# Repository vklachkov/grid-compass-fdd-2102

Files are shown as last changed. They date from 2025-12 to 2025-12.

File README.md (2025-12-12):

# Reverse Engineering of 2102 Floppy Drive

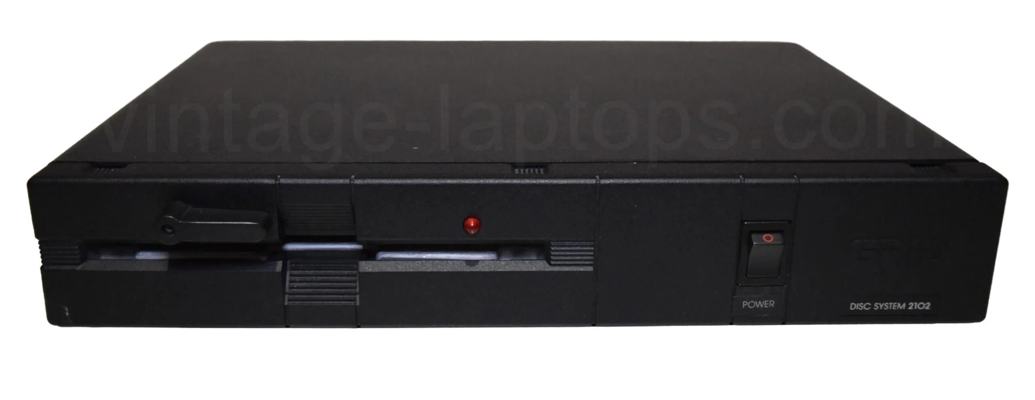
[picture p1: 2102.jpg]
Photo of 2102

Photo was taken from the [vintage-laptops.com](https://vintage-laptops.com/en/per-gridcompass1121/).

This is a project to reverse engineer the 2102 floppy drive from 1983 for the GRiD Compass laptop. The project is for fun and to fix bugs in the [blackgpib](https://github.com/vklachkov/blackgpib) project.

Current status:

2. Complete schematics by [@JDat](https://github.com/JDat).
3. Full dump of PAL chip by [@JDat](https://github.com/JDat).
4. Firmware reverse engineering is ~80% complete by [me](https://github.com/vklachkov) and Kirill from [Xecut Hackspace](https://xecut.me/).

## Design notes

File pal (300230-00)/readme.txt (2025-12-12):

This folder contains information about
GRiD 300230-00 (PAL16L8) IC used in 2102 Portable floppy.

pal16l8.txt - initial dump made with arduino EEPROM programmer/dumper
This file in compatible with Logic Friday truth table input format.
Dump made on 2024.07.21. 09:30 UTC

pal16l8.bin - binary reperesentation of 300230-00 it we assume it is
ROM lookup table (similar approach to Commodore PLA address chip).

16L8_pins_bin_dump.jpg - pinout for assmuming it is ROM lookup table

PAL16L8_dumper folder contains arduino source code and schematics for dumper

c_equvalent folder contains Simple C program to generate the same binary file
as pal16l8.bin and for future research

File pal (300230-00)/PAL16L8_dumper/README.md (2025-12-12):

This is quick and dirty project
to convert my EEPROM programmer
into PAL/GAL dumper/reversing/research platform

Arduino I2C EEPROM Programmer for SST39SF010A/SST39SF020A/SST39SF040A AT29C010A

This code should be compiled by the Arduino IDE and run on an Arduino UNO.

Code based on:
http://danceswithferrets.org/geekblog/?page_id=903
https://github.com/TSwimson/eeprom-writer

and Chris Baird’s Python script

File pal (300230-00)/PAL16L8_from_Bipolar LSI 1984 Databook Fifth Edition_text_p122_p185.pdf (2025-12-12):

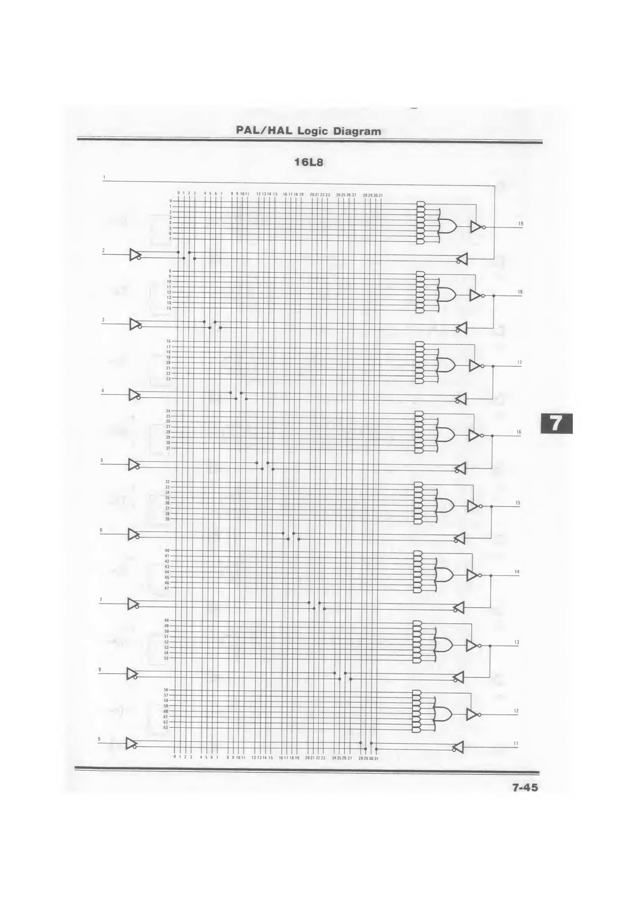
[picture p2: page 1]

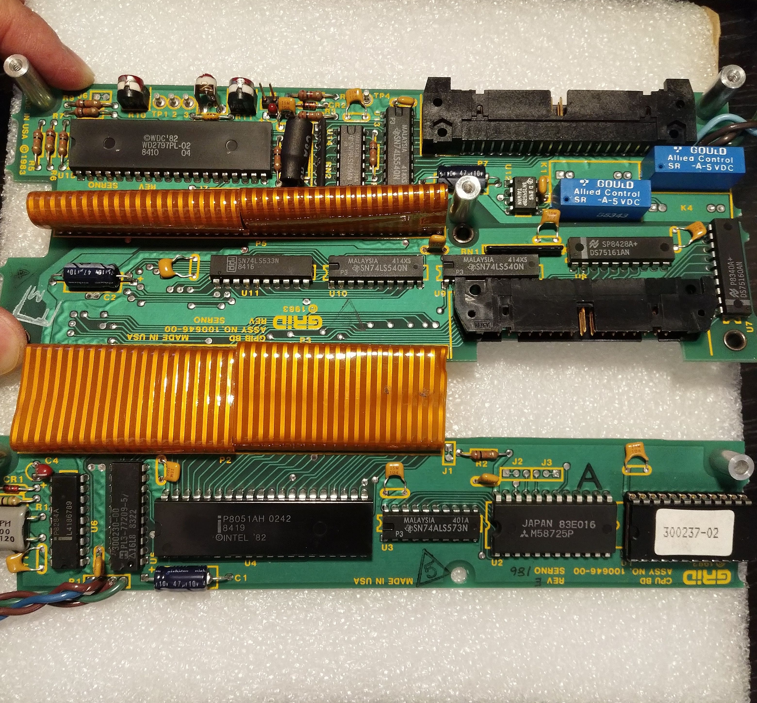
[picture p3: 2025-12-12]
photos/2102 (1983) boards.jpg

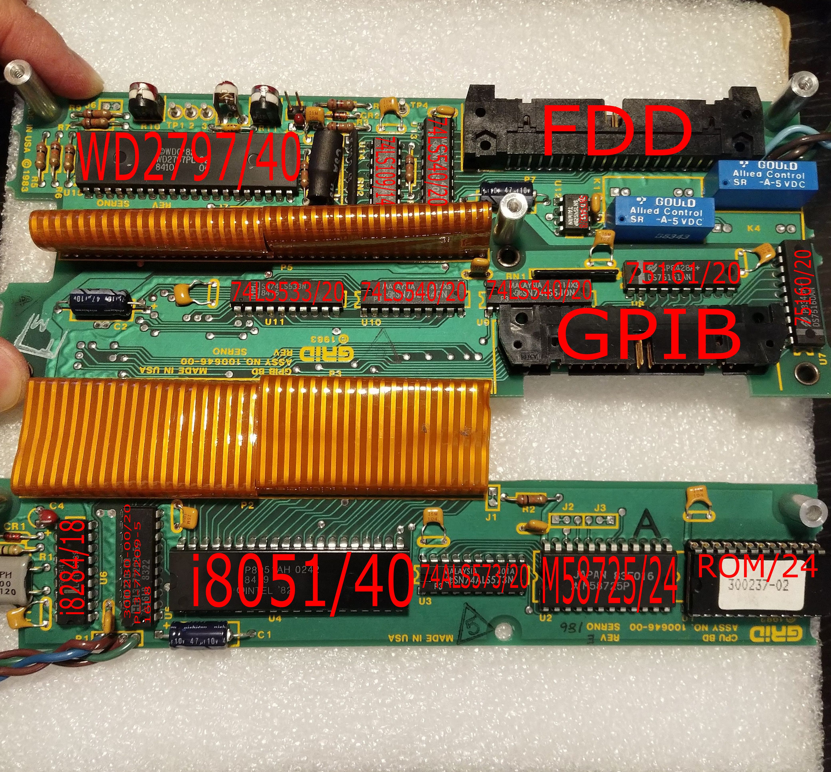
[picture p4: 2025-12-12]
photos/2102 (1983) boards with ICs indentification.jpg

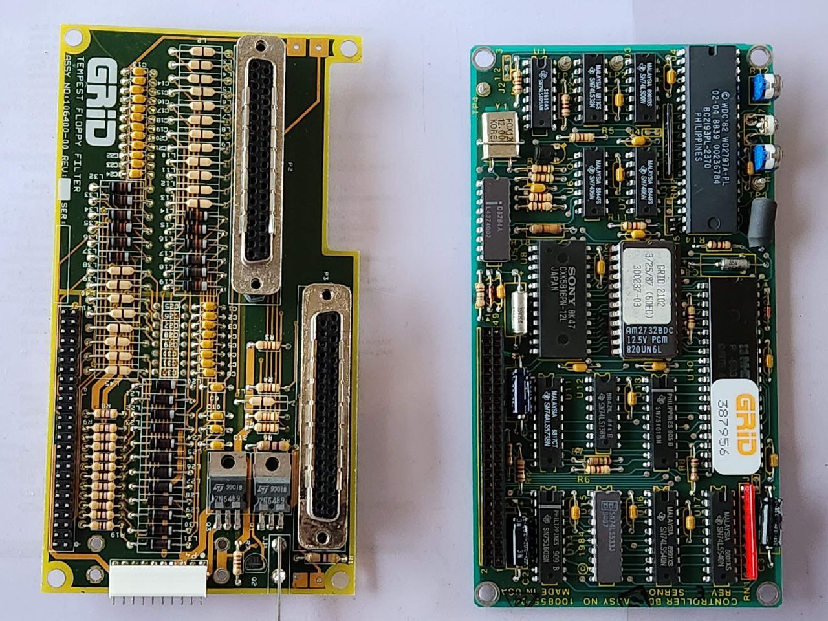
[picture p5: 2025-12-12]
photos/2107 (1990) boards top.jpg

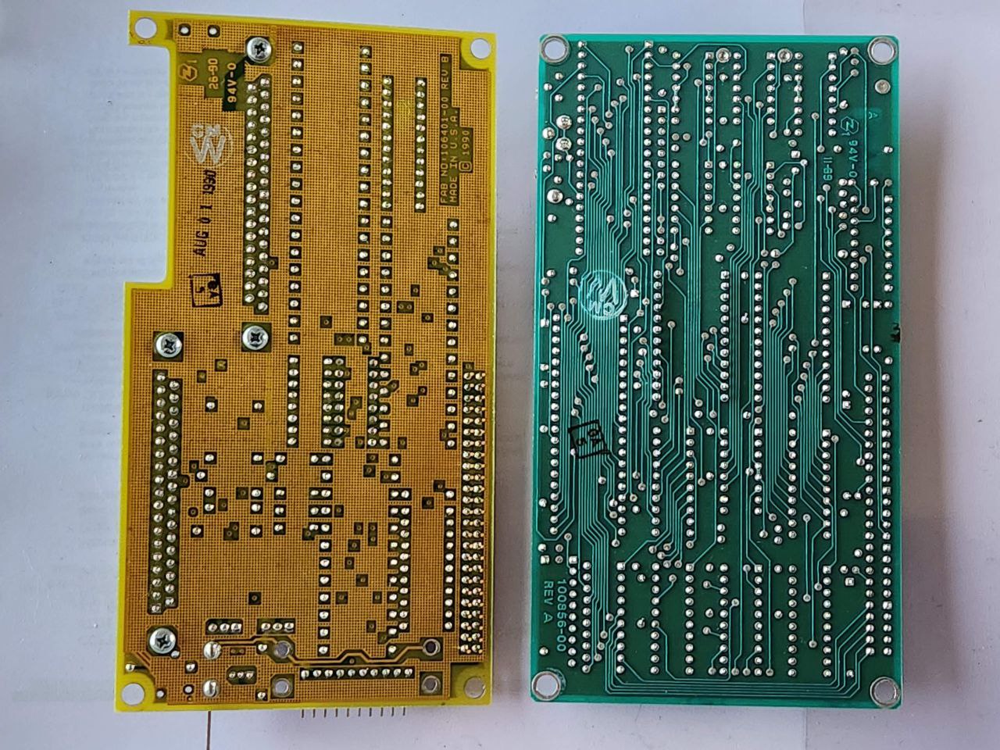
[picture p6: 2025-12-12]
photos/2107 (1990) boards bottom.jpg

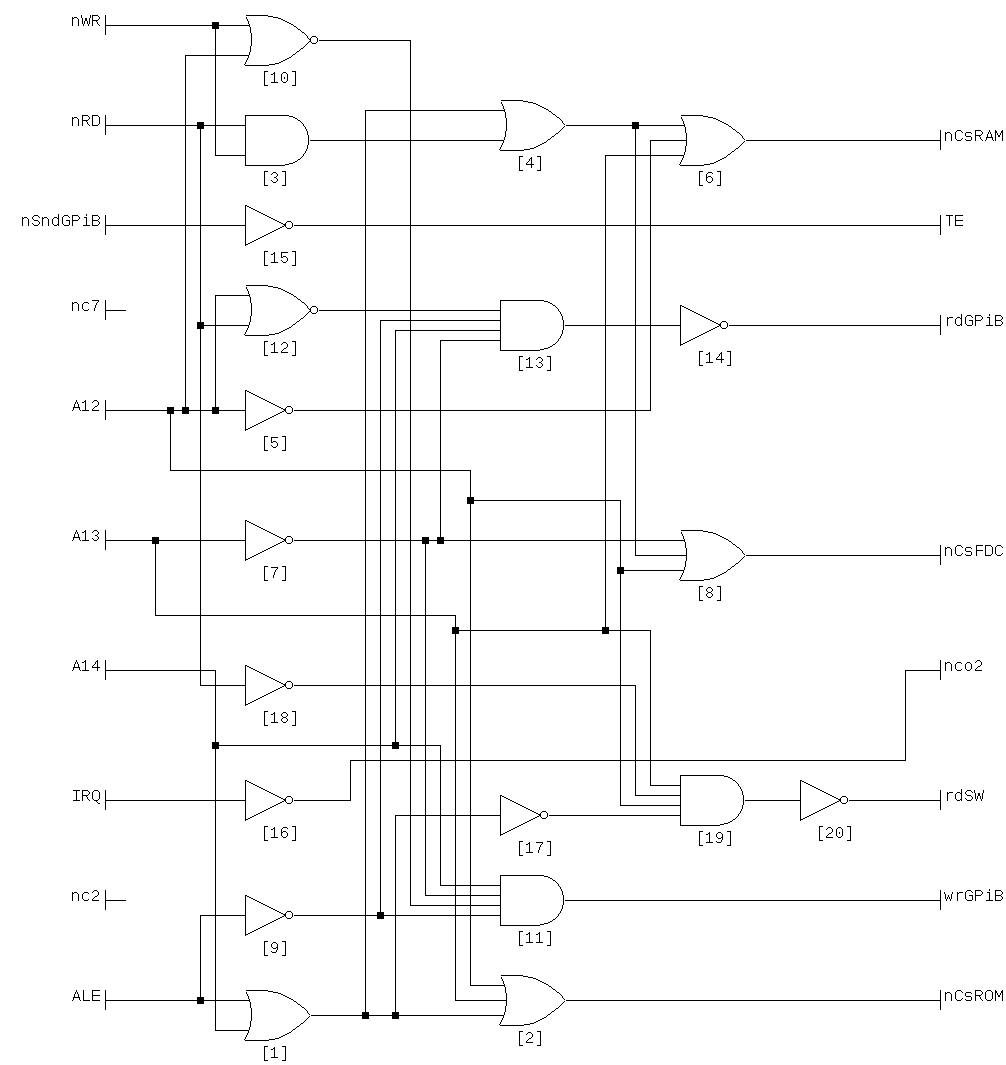
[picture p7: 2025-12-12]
pal (300230-00)/PAL16L8_300230-00.bmp

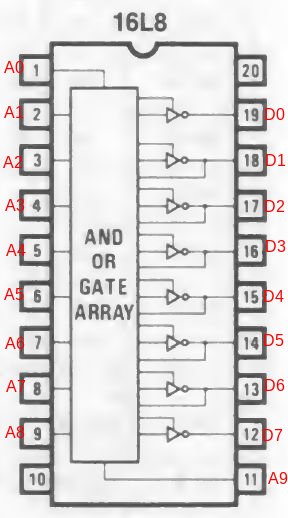
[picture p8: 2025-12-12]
pal (300230-00)/16L8_pins_bin_dump.jpg

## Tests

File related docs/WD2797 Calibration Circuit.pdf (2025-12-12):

WD2797 Calibration Circuit

This is a simple little circuit that can be built with 5 standard 74LS TTL IC’s and a 40MHz crystal oscillator. The circuit does not require any adjustments and circuit layout is not critical. The circuit can be built on a wire-wrap board or any other type of project board. A 5-volt regulator is included so that the board can be powered from a variety of power sources. The prototype was built on a solder-less breadboard and the final board was built on a Radio Shack project board and power by a 9-volt battery.

Once the circuit is built use the following procedure to set the Pulse Width Modulator and VCO of the WD2797 as follows:

1. Set the TEST pin, pin-22, of the WD2797 to logic high.
2. Ensure that the 5/8 pin, pin-17, and the /DDEN pin, pin-37, are both grounded.
3. Strobe the master reset pin, pin-19.
4. Set the TEST pin, pin-22, of the WD2797 to a logic low.
5. Set a jumper between pins 1 and 2 of W1 and W2 on the calibration circuit. W3 is not used at this time.
6. Connect Pin-2 of J1 to ground on the WD2797 board and pin-1 of J1 to pin-29 of the WD2797.
7. Turn the potentiometer on pin-18 counter clockwise, CCW, until the LED on the calibration circuit is OFF.
8. Now turn the potentiometer clockwise, CW, until the LED is ON.
9. Continue turning the potentiometer CW until the LED turns OFF again.
10. Now turn the potentiometer CCW until the LED is COMPLETELY ON and stop. Do not turn the potentiometer any further. If you turn the potentiometer adjustment CW a tiny bit you should see the LED dim down. Turn the adjustment CCW just enough to get the LED on at full brightness.
11. On the calibration circuit move the jumpers on W1 and W2 to pins 2 and 3. Install a jumper on pins 1 and 2 of W3.
12. Connect pin-1 of J1 on the calibration circuit to pin-16 of the WD2797.
13. Adjust the variable capacitor on pin-26 of the WD2797 until the LED is on. This set the variable capacitor to minimum capacitance.

14. Now move the jumper on W3 of the calibration circuit to pins 2 and 3.
15. Now turn the variable capacitor CW until the LED turns ON. Continue turning the adjustment CW until the LED turns OFF. Now turn the adjustment CCW to a point midway between the two points at which the LED is OFF. Lets say that the LED turns ON at the 10 o’clock position and turns OFF at the 12 o’clock position. Turn this adjustment to the 11 o’clock position.
16. Disconnect the calibration circuit from the WD2797 and set the TEST pin, pin-22, to logic high.

That’s it your finished. If you have scope you can double check the adjustments as you make them.

It is hoped that this circuit will help those that do not have access to a scope to make the adjustments to the WD2797 FDC chip.

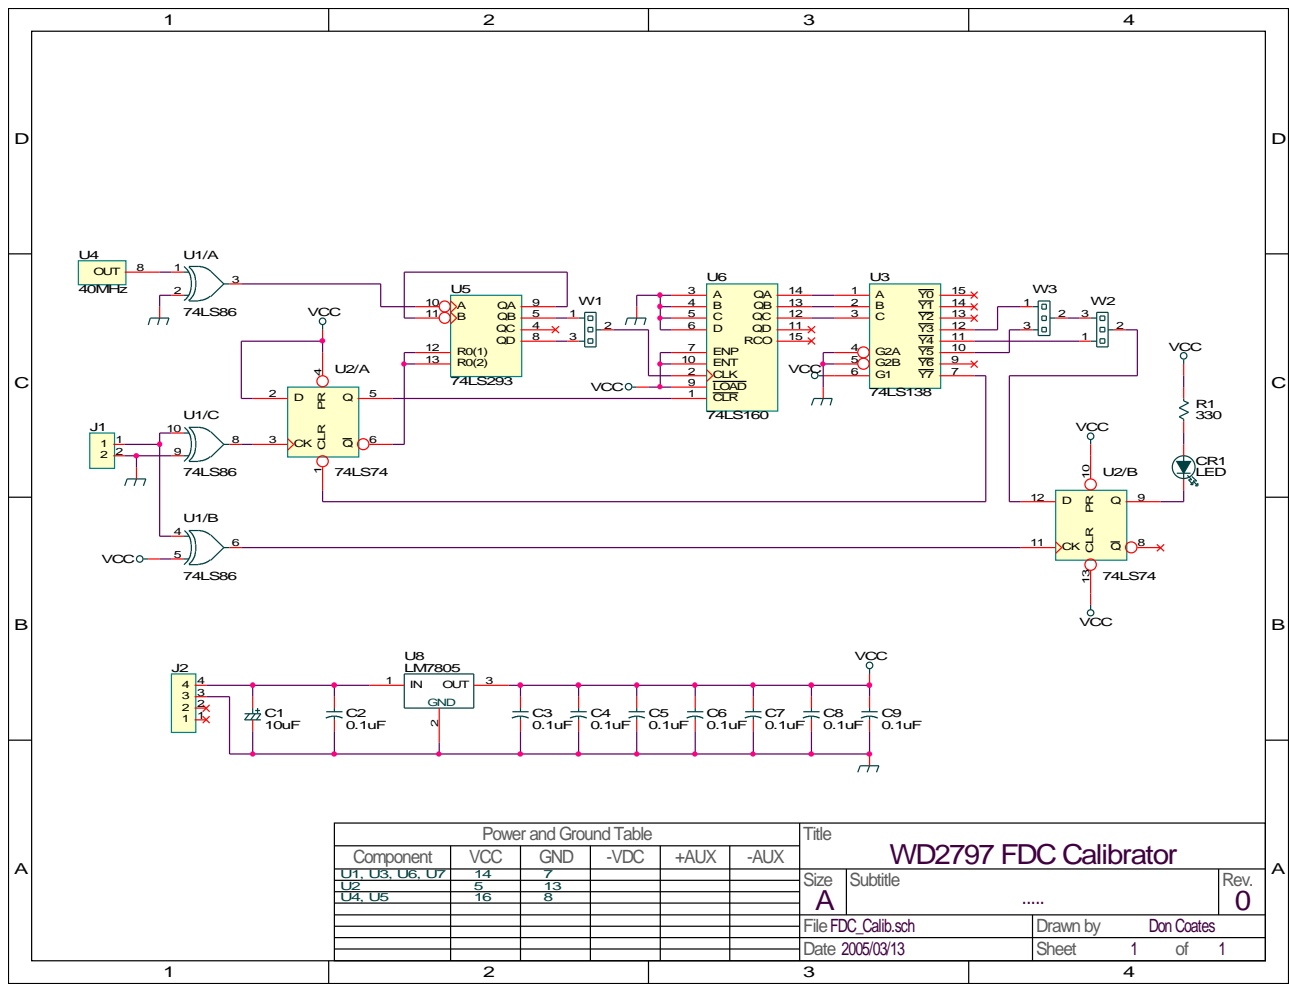
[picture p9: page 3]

Power and Ground Table

14
5 | 13
16 | 8

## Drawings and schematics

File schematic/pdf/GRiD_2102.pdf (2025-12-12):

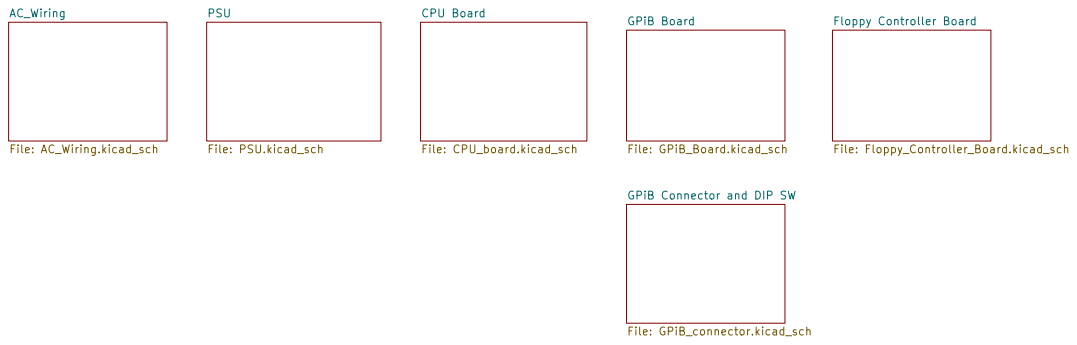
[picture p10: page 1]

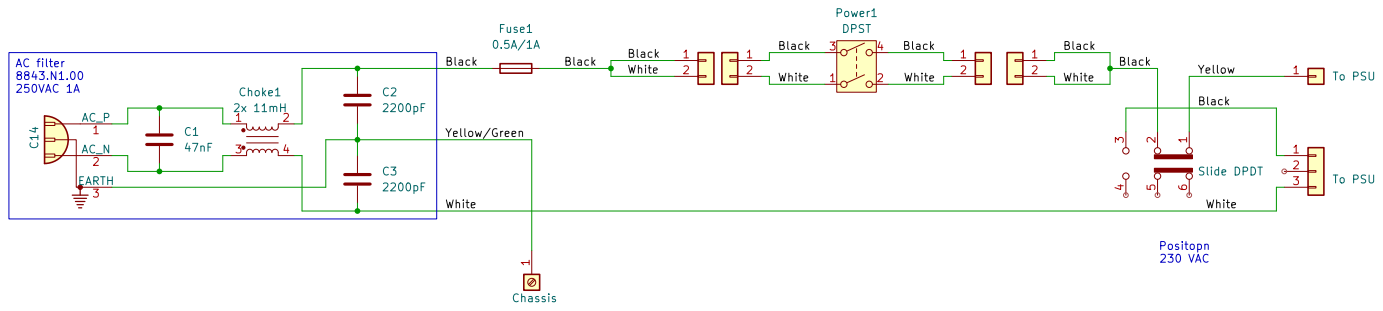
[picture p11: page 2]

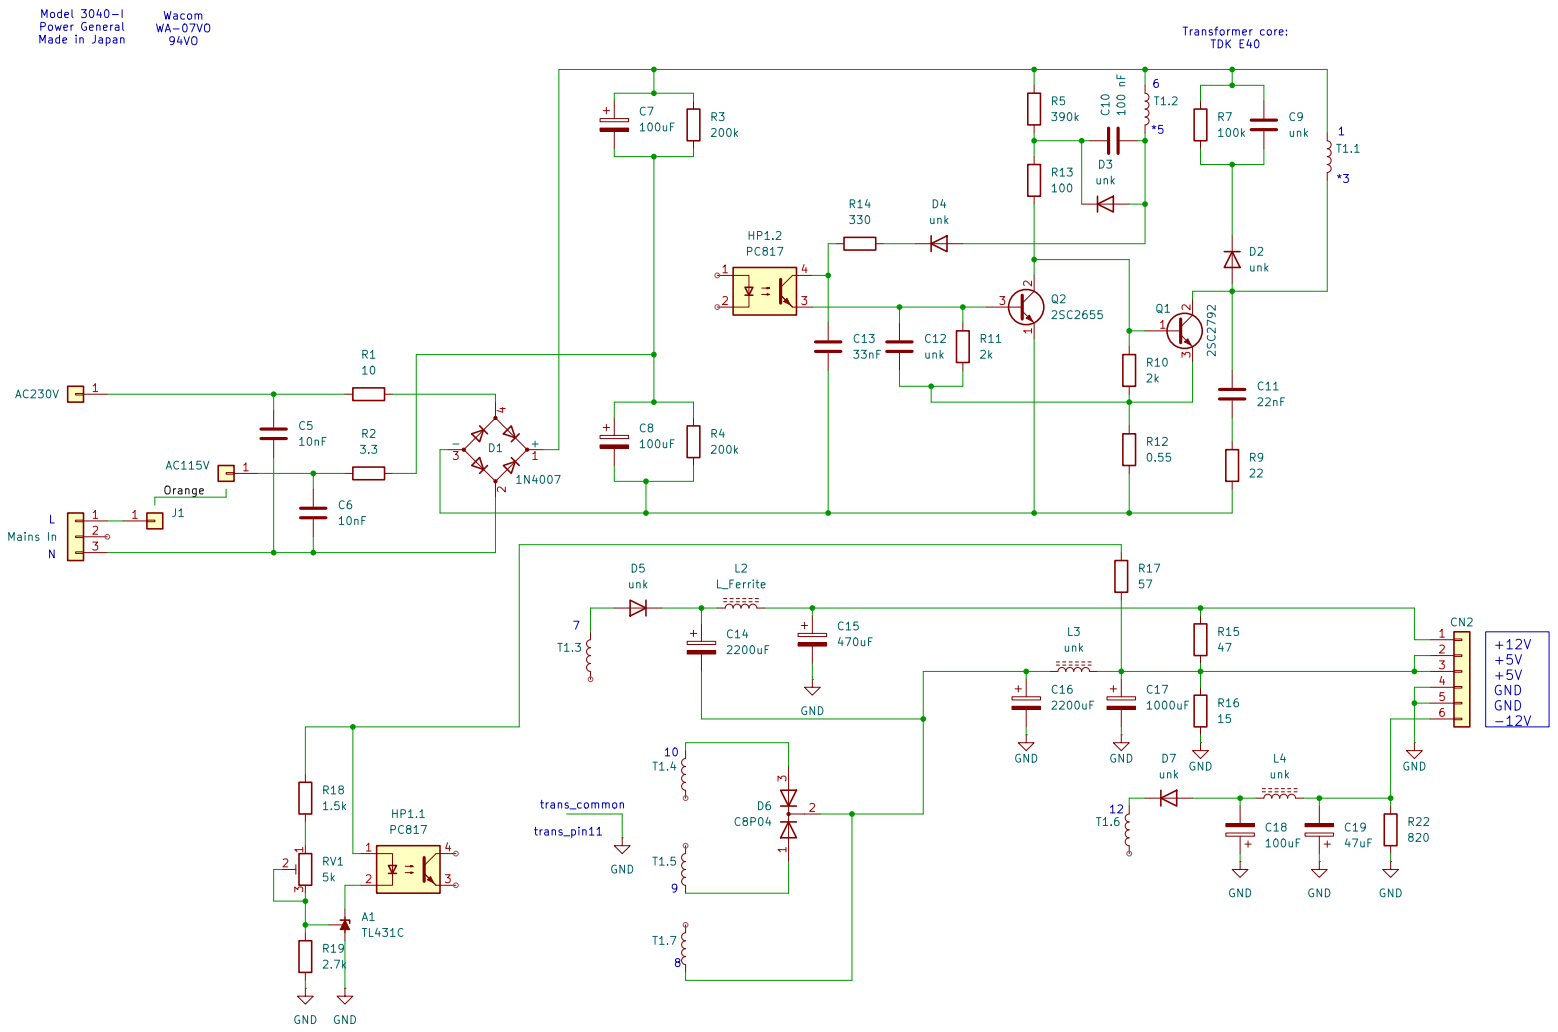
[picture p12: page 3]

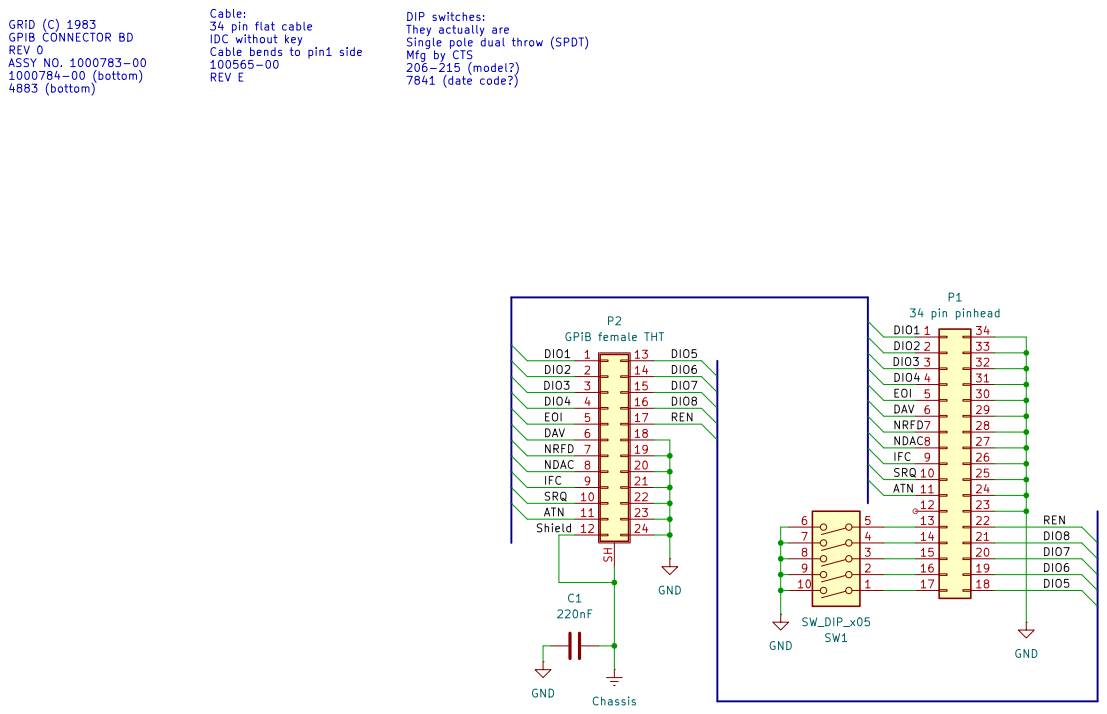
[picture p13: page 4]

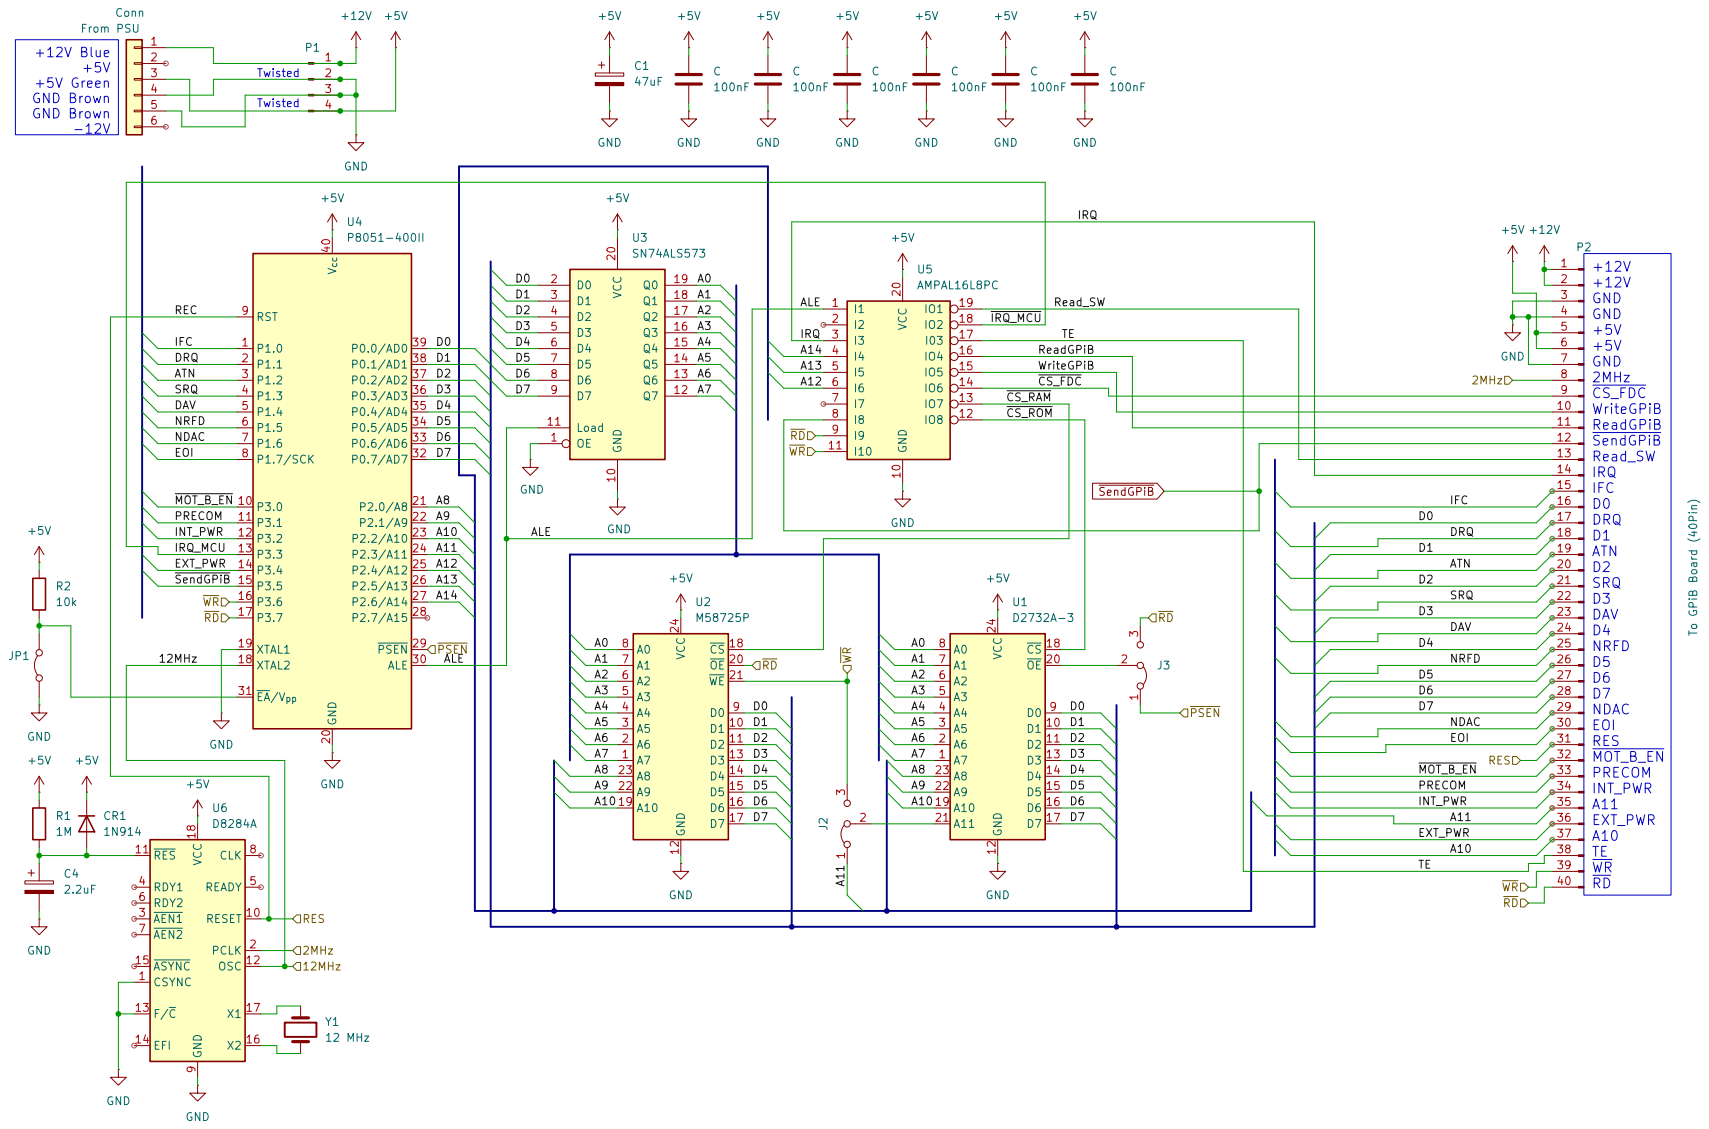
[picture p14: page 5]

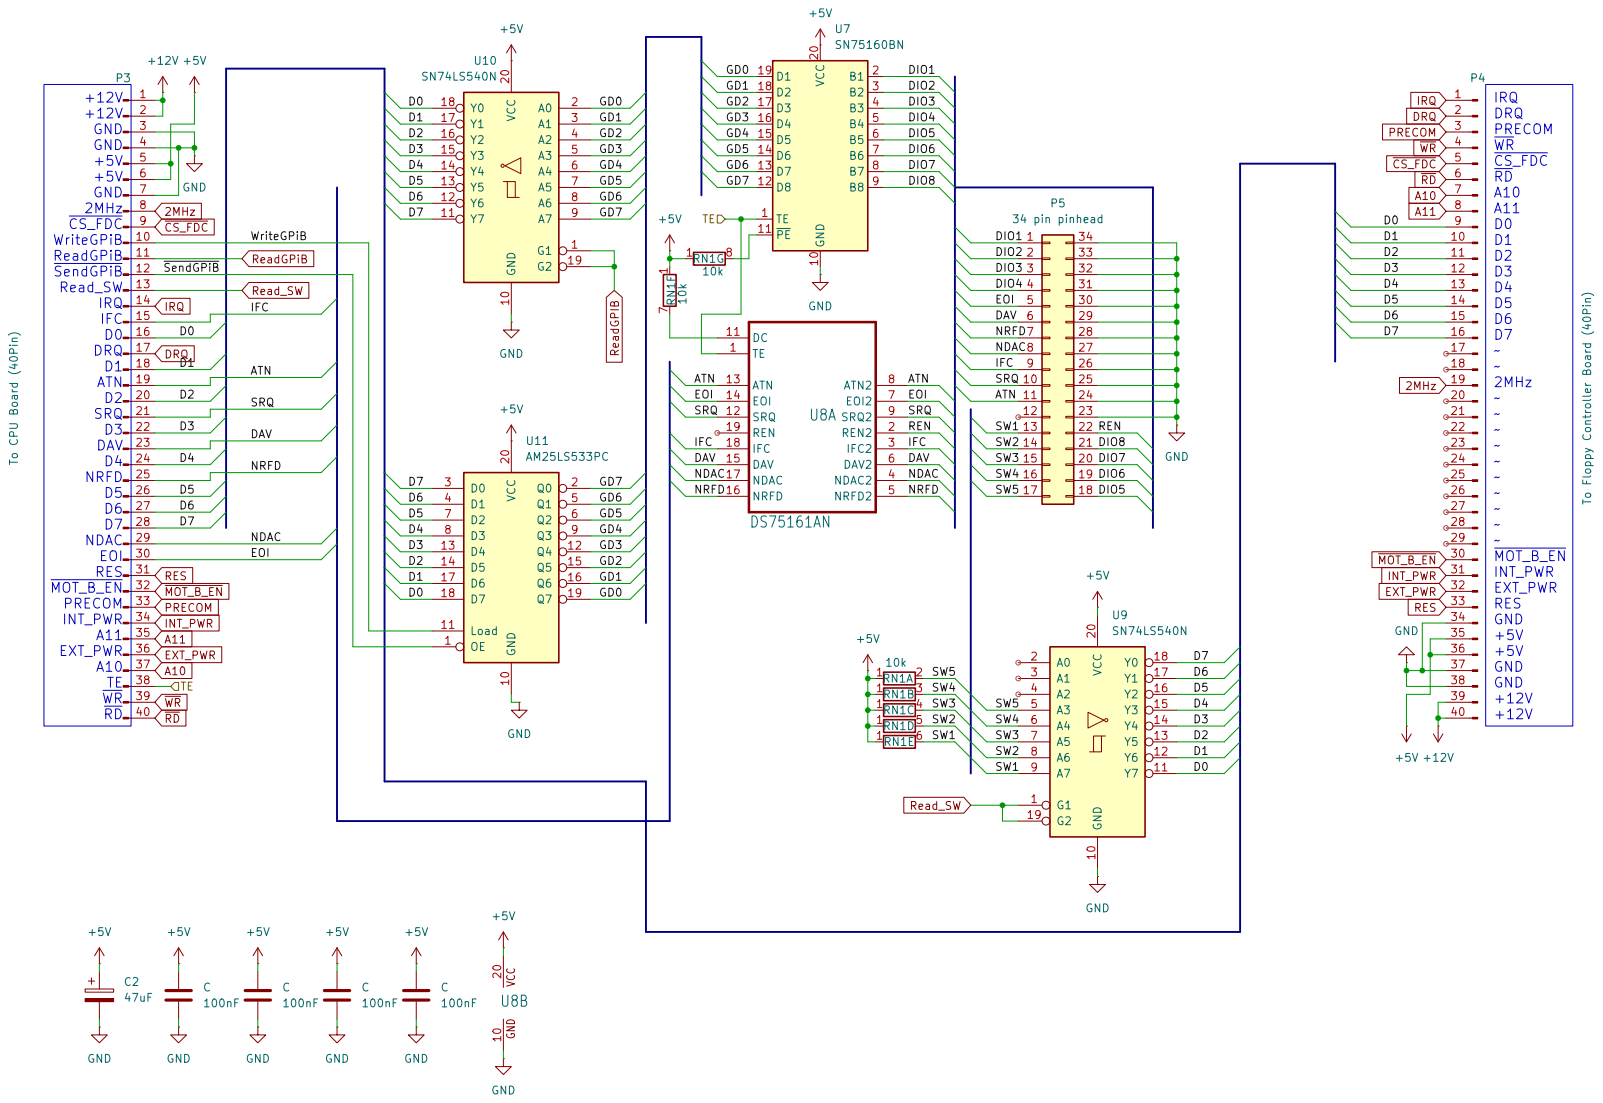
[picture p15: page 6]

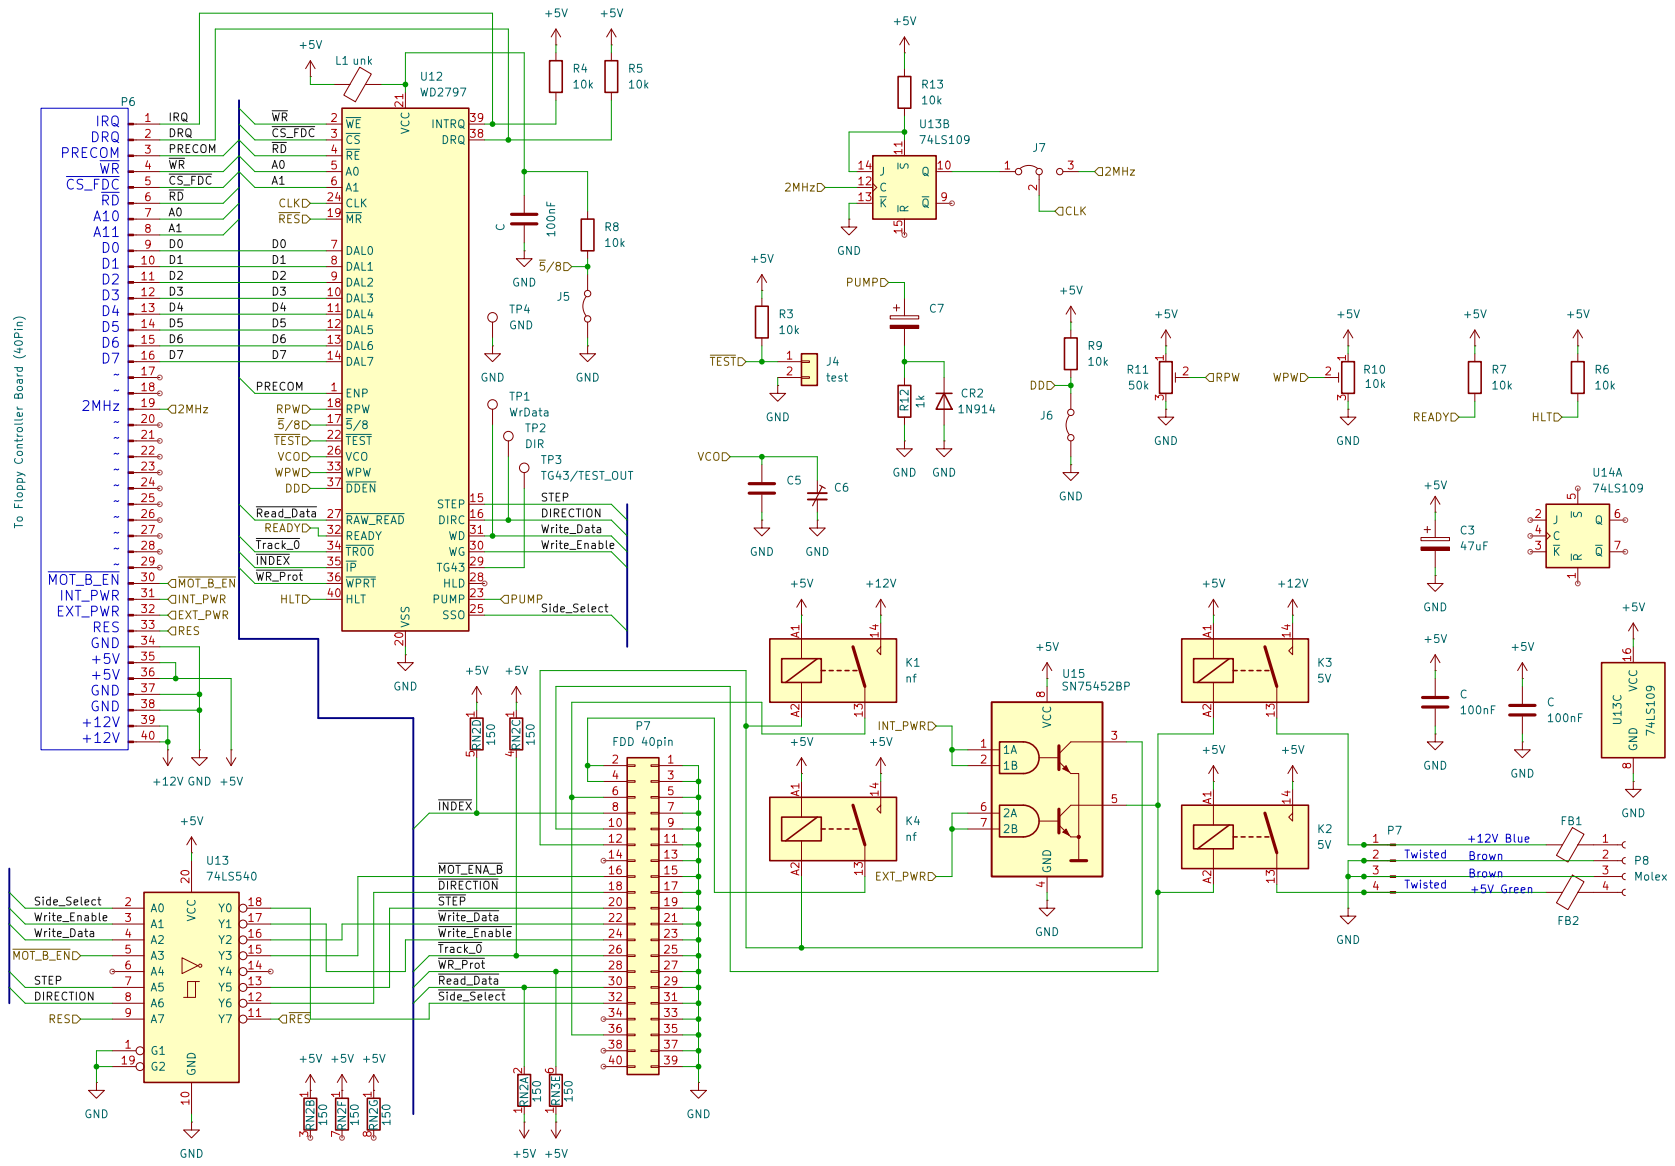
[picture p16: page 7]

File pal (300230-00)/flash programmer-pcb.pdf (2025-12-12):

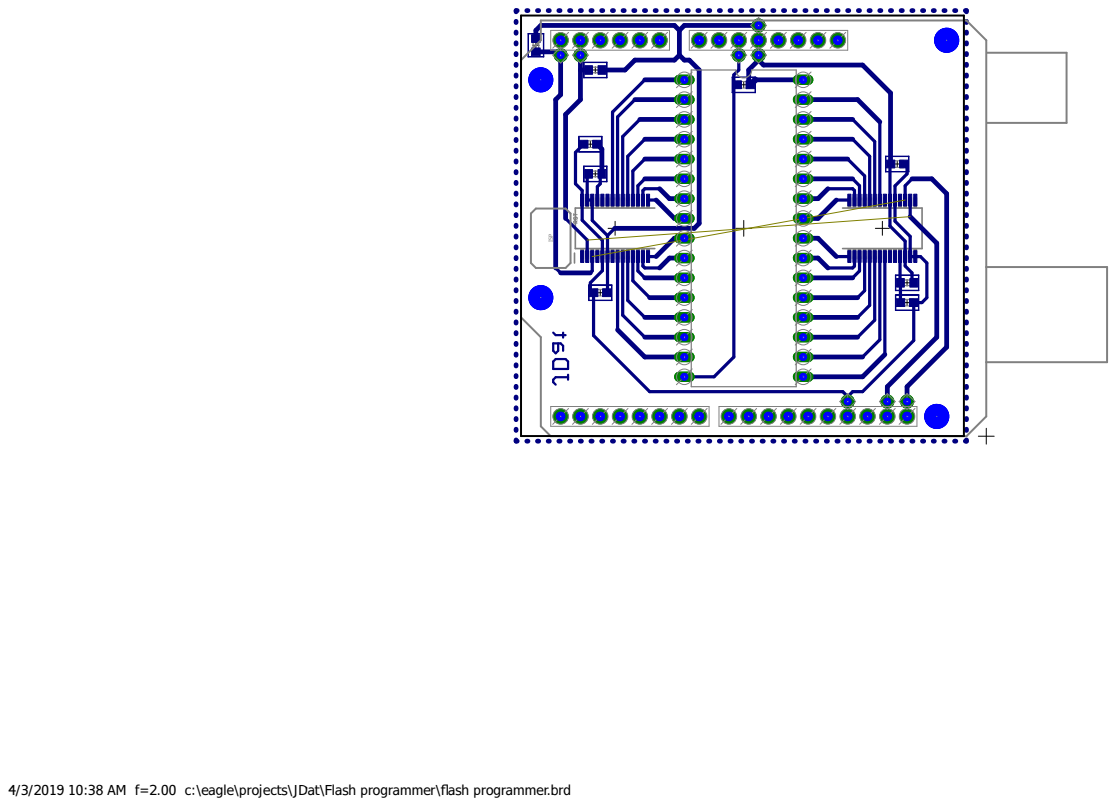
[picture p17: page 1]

4/3/2019 10:38 AM f=2.00 c:\eagle\projects\JDat\Flash programmer\flash programmer.brd

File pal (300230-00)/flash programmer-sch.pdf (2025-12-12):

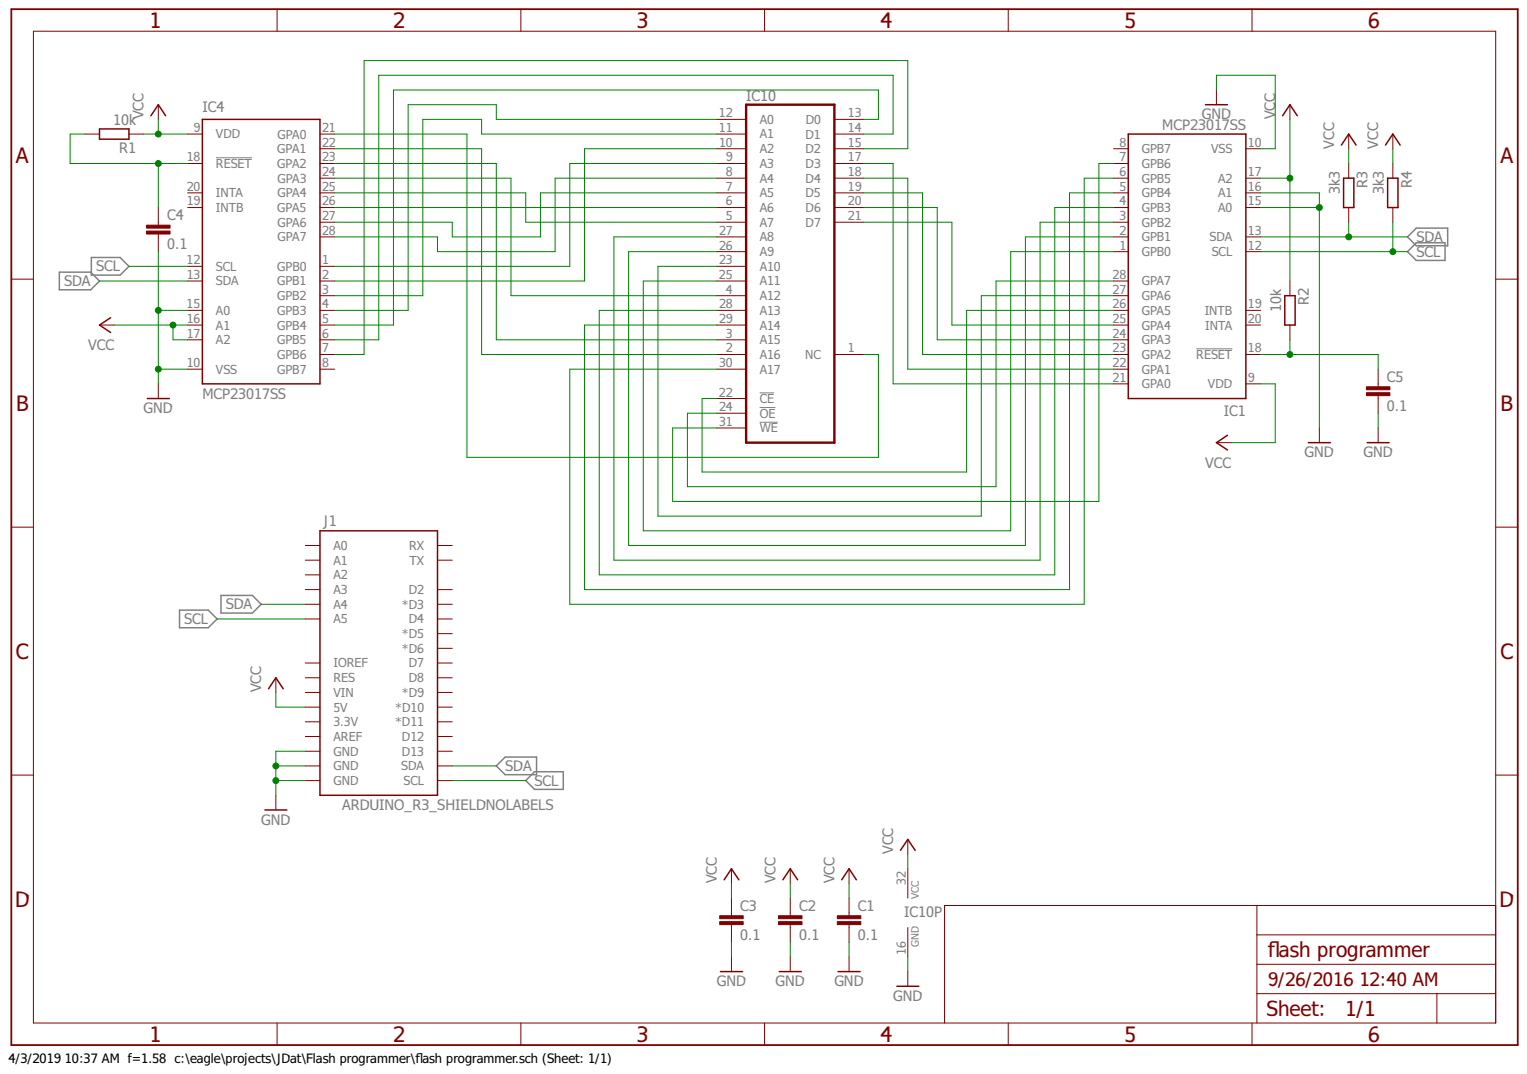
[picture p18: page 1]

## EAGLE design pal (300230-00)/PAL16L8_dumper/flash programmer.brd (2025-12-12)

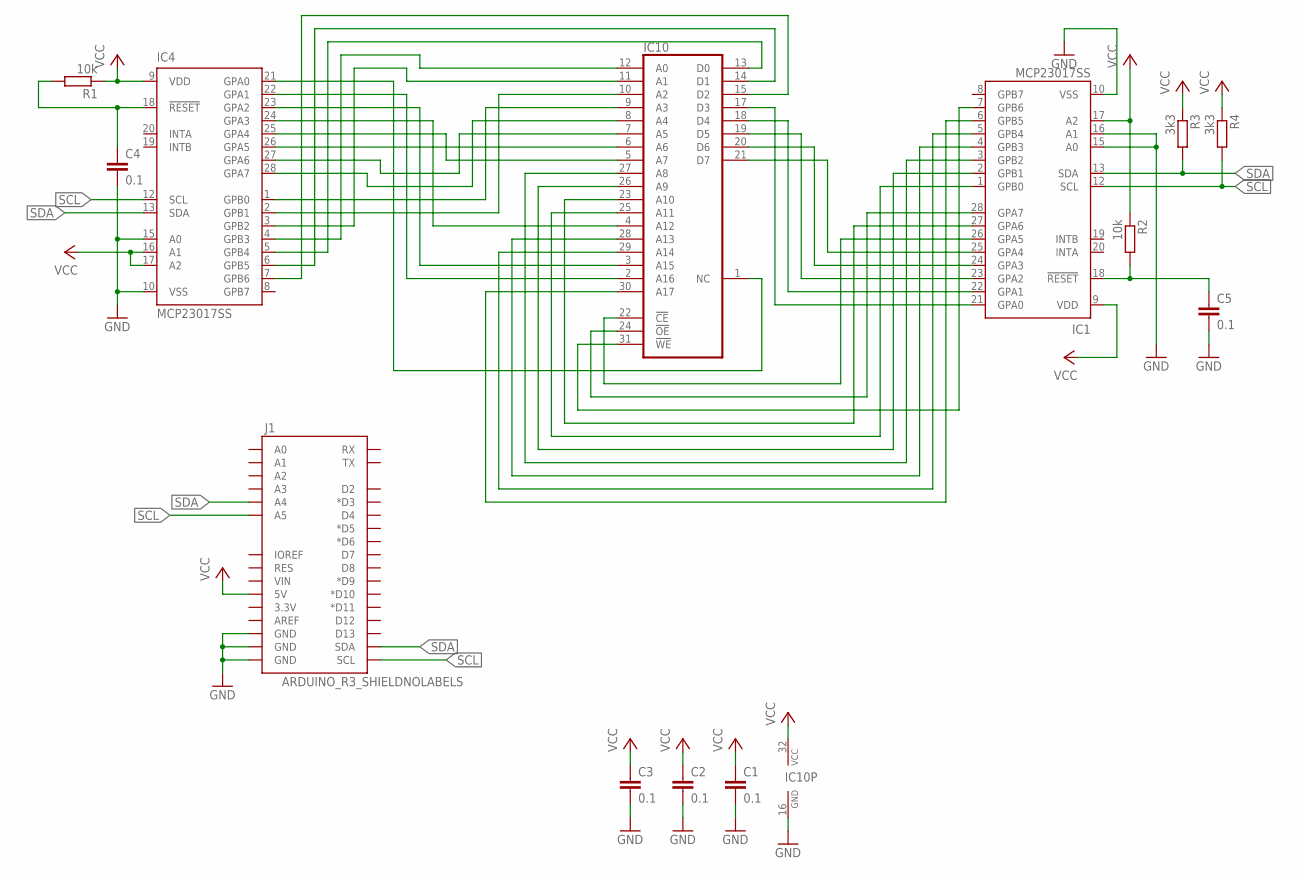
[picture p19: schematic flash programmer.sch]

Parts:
C1, C2, C3, C4, C5: 0.1; C0603
IC1, IC4: MCP23017SS; SSOP28
IC10: SST39SF020A-70-4C-PHE; DIL32
J1: ARDUINO_R3_SHIELDNOLABELS; UNO_R3_SHIELD_NOLABELS
R1, R2: 10k; R0603
R3, R4: 3k3; R0603

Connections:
GND: C1.2, C2.2, C3.2, C4.2, C5.2, IC1.10 (VSS), IC1.15 (A0), IC1.16 (A1), IC4.10 (VSS), IC4.15 (A0), IC10.16 (GND), J1.GND@0 (GND), J1.GND@1 (GND), J1.GND@2 (GND)
unnamed: IC4.21 (GPA0), IC10.1 (NC)
unnamed: IC4.22 (GPA1), IC10.2 (A16)
unnamed: IC4.23 (GPA2), IC10.3 (A15)
unnamed: IC4.24 (GPA3), IC10.4 (A12)
unnamed: IC4.25 (GPA4), IC10.5 (A7)
unnamed: IC4.26 (GPA5), IC10.6 (A6)
unnamed: IC4.27 (GPA6), IC10.7 (A5)
unnamed: IC4.28 (GPA7), IC10.8 (A4)
unnamed: IC4.2 (GPB1), IC10.10 (A2)
unnamed: IC4.1 (GPB0), IC10.9 (A3)
unnamed: IC4.3 (GPB2), IC10.11 (A1)
unnamed: IC4.4 (GPB3), IC10.12 (A0)
unnamed: IC4.5 (GPB4), IC10.13 (D0)
unnamed: IC4.6 (GPB5), IC10.14 (D1)
unnamed: IC4.7 (GPB6), IC10.15 (D2)
unnamed: IC1.21 (GPA0), IC10.17 (D3)
unnamed: IC1.22 (GPA1), IC10.18 (D4)
unnamed: IC1.23 (GPA2), IC10.19 (D5)
unnamed: IC1.24 (GPA3), IC10.20 (D6)
unnamed: IC1.25 (GPA4), IC10.21 (D7)
unnamed: IC1.26 (GPA5), IC10.22 (!CE)
unnamed: IC1.27 (GPA6), IC10.23 (A10)
unnamed: IC1.28 (GPA7), IC10.24 (!OE)
unnamed: IC1.1 (GPB0), IC10.25 (A11)
unnamed: IC1.2 (GPB1), IC10.26 (A9)
unnamed: IC1.3 (GPB2), IC10.27 (A8)
unnamed: IC1.4 (GPB3), IC10.28 (A13)
unnamed: IC1.5 (GPB4), IC10.29 (A14)
unnamed: IC1.6 (GPB5), IC10.30 (A17)
unnamed: IC1.7 (GPB6), IC10.31 (!WE)
unnamed: C5.1, IC1.18 (!RESET), R2.2
unnamed: C4.1, IC4.18 (!RESET), R1.2
SCL: IC1.12 (SCL), IC4.12 (SCL), J1.A5, J1.SCL, R4.2
SDA: IC1.13 (SDA), IC4.13 (SDA), J1.A4, J1.SDA, R3.2
VCC: C1.1, C2.1, C3.1, IC1.9 (VDD), IC1.17 (A2), IC4.9 (VDD), IC4.16 (A1), IC4.17 (A2), IC10.32 (VCC), J1.5V, R1.1, R2.1, R3.1, R4.1

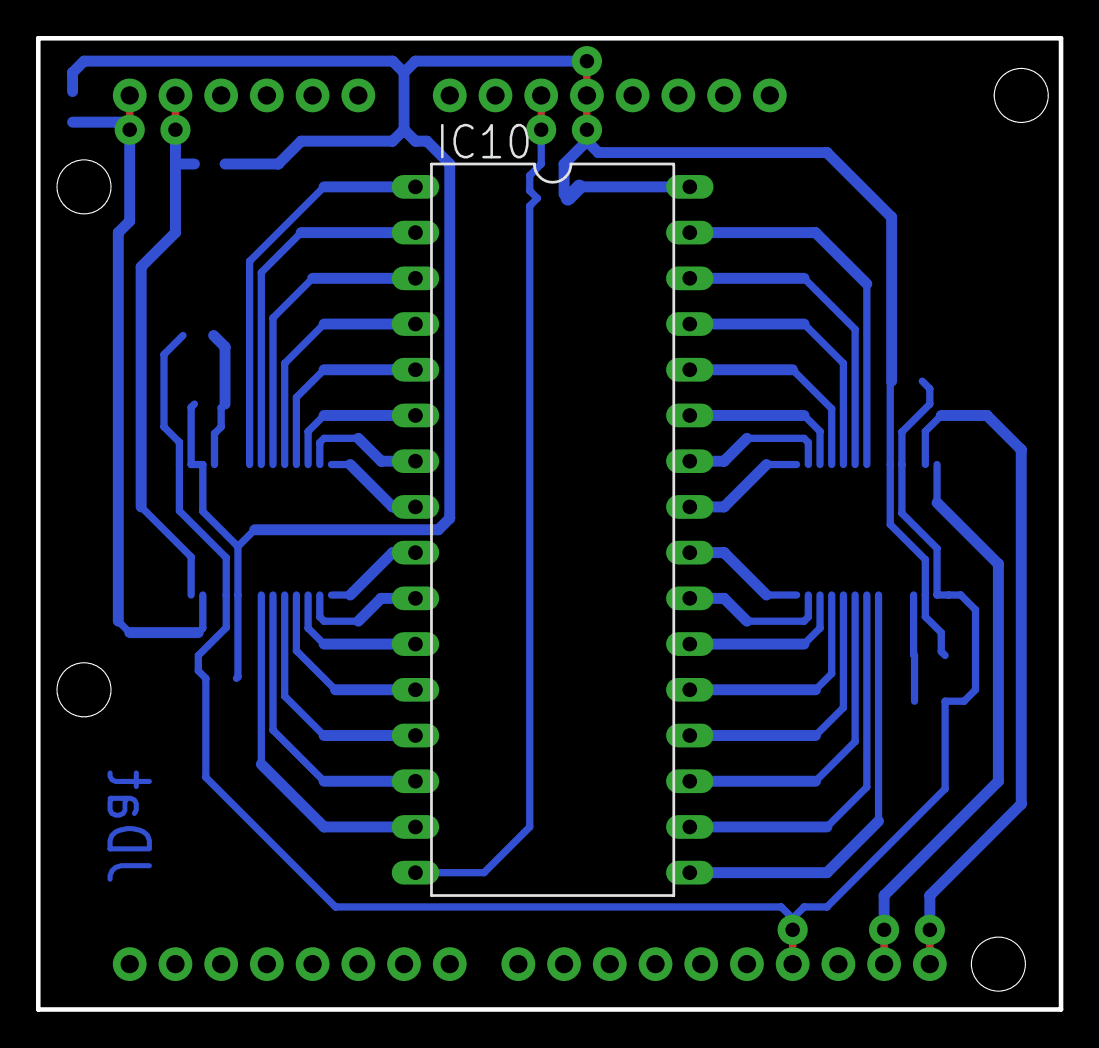
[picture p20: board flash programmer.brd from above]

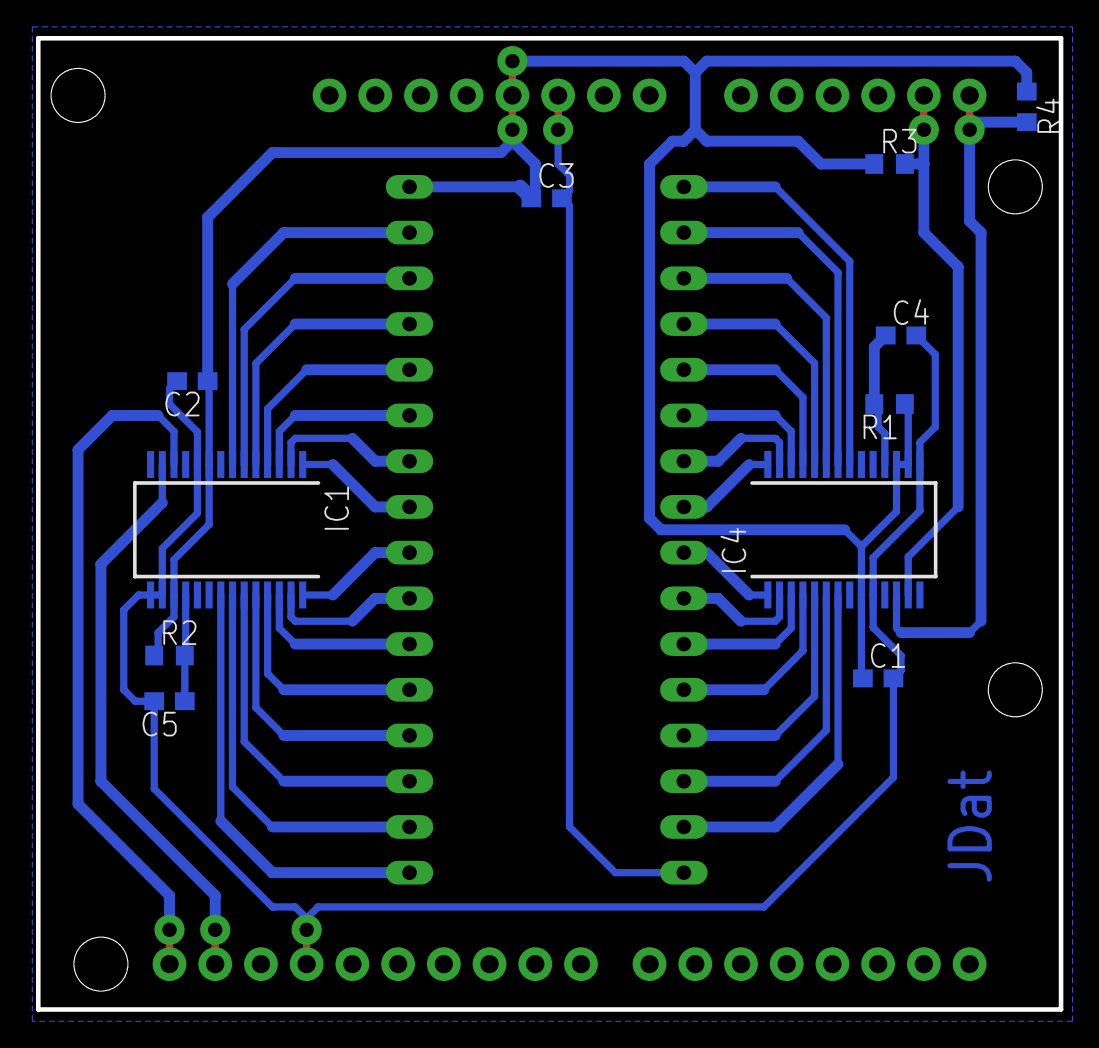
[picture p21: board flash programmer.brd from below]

Board: 2 copper layers, 56.8 x 54.0 mm, 13 parts (11 on the bottom side), 36 nets.

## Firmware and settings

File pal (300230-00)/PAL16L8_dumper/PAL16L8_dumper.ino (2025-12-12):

/*
// Based and core Written by K Adcock.
// http://danceswithferrets.org/geekblog/?page_id=903
//
// I2C modifications by JDat
*/
#include "pindefine.h"
#include "Adafruit_MCP23017.h"

uint16_t ic1out=0xFFFF;
uint16_t ic2out=0xFFFF;

Adafruit_MCP23017 mcp1;
Adafruit_MCP23017 mcp2;

void setup() {
  Serial.begin(115200);

  //Wire.setClock(400000);
  Wire.setClock(1000000);
  //Wire.setClock(3400000);

  mcp1.begin(IC1);
  mcp2.begin(IC2);


  for (uint8_t i = 0; i < 16; i++) {
    mcp1.pinMode(i,INPUT_PULLUP);
    mcp2.pinMode(i,INPUT_PULLUP);
  }

/*
  // for individual pin test
  while (true) {
    uint8_t i = 0;

    if (dataRoute[i]==IC1) {
      bitSet(ic1out,dataArray[i]);
    } else if (dataRoute[i]==IC2) {
      bitSet(ic2out,dataArray[i]);
    }
    mcp1.writeGPIOAB(ic1out);
    mcp2.writeGPIOAB(ic2out);   
    delay(2000);

    if (dataRoute[i]==IC1) {
      bitClear(ic1out,dataArray[i]);
    } else if (dataRoute[i]==IC2) {
      bitClear(ic2out,dataArray[i]);
    }
    mcp1.writeGPIOAB(ic1out);
    mcp2.writeGPIOAB(ic2out);   
    
    delay(2000);
  }
*/

  pinMode(LED_BUILTIN, OUTPUT);

  // set address lines as outputs
  for (uint8_t i=0;i<=9;i++) {
    if (addrRoute[i]==IC1) {
      mcp1.pinMode(addrArray[i],OUTPUT);
      
    } else if (addrRoute[i]==IC2) {
      mcp2.pinMode(addrArray[i],OUTPUT);
    }
  }

  // set data lines as inputs
  for (uint8_t i=0;i<=7;i++) {
    if (dataRoute[i]==IC1) {
      mcp1.pinMode(dataArray[i],INPUT);
    } else if (dataRoute[i]==IC2) {
      mcp2.pinMode(dataArray[i],INPUT);
    }
  }

  // start reading
  digitalWrite(LED_BUILTIN, HIGH);
  //Serial.println("A9,A8,A7,A6,A5,A4,A3,A2,A1,A0,,D7,D6,D5,D4,D3,D2,D1,D0");
  Serial.println();
  Serial.println("nWR,nRD,nSndGPiB,nc7,A12,A13,A14,IRQ,nc2,ALE,,nCsROM,nCsRAM,nCsFDC,wrGPiB,rdGPiB,TE,nco2,rdSW");

  // start actual reading
  uint8_t result;
  for (long i = 0; i <= 1023; i++) {
    result = ReadByteFrom(i);
    printValue(i, result);
  }
  //end actual reading
  
  Serial.println();
  digitalWrite(LED_BUILTIN, LOW);
  //end reading

  // we are done halt (looping)
  while (true) {
    ;
  }
}

void loop() {
  ;
}

void printValue(long addr, uint8_t data) {
   for (int8_t i = 9; i >= 0; i--) {
      Serial.print(bitRead(addr, i) ? "1" : "0");
      Serial.print(",");
   }
   
   Serial.print(",");

   for (int8_t i = 7; i >= 1; i--) {
      Serial.print(bitRead(data, i) ? "1" : "0");
      Serial.print(",");
   }
   Serial.println(bitRead(data, 0));
   
}


// this function assumes that data lines have already been set as INPUTS
byte ReadByteFrom(long addr) {
  SetAddress(addr);
  byte b = ReadData();
  return b;
}

void SetAddress(long a) {
  for (uint8_t i = 0; i <= 9; i++) {
    if (addrRoute[i] == IC1) {
      if ( a & long(round(pow(2,i))) ) {
        bitSet(ic1out,addrArray[i]);
      } else {
        bitClear(ic1out,addrArray[i]);
      }
    } else if (addrRoute[i] == IC2) {
      if ( a & long(round(pow(2,i))) ) {
        bitSet(ic2out, addrArray[i]);
      } else {
        bitClear(ic2out, addrArray[i]);
      }
    }
  }

  mcp1.writeGPIOAB(ic1out);
  mcp2.writeGPIOAB(ic2out);
}

// this function assumes that address is already set
byte ReadData() {
  byte result = 0;

  for (uint8_t i = 0; i <= 7; i++) {
    if (dataRoute[i] == IC1) {
      if ( mcp1.digitalRead(dataArray[i]) ) {
        bitSet(result, i);
      }
    } else if (dataRoute[i] == IC2) {
      if ( mcp2.digitalRead(dataArray[i]) ) {
        bitSet(result, i);
      }      
    }
  }
  return(result);
}

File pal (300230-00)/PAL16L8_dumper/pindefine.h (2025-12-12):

#ifndef _programmer_pindefine_H_
#define _programmer_pindefine_H_

#include <Arduino.h>

#define IC1         4   // IC addr1 0x24
#define IC2         6   // IC addr2 0x26

#define addrpin0    6
#define addrpin1    7
#define addrpin2    8
#define addrpin3    9
#define addrpin4    10
#define addrpin5    11
#define addrpin6    12
#define addrpin7    13
#define addrpin8    14

#define addrpin9    0

#define datapin7    1
#define datapin6    2
#define datapin5    3
#define datapin4    4
#define datapin3    5
#define datapin2    6
#define datapin1    7
#define datapin0    8

//#define addrpin6    5
//#define addrpin7    4

//#define addrpin8    10
//#define addrpin9    9

uint8_t addrArray[]=  {addrpin0,addrpin1,addrpin2,addrpin3,
                      addrpin4,addrpin5,addrpin6,addrpin7,
                      addrpin8,addrpin9};

uint8_t addrRoute[]=  {IC2,IC2,IC2,IC2,
                      IC2,IC2,IC2,IC2,
                      IC2,IC1};

uint8_t dataArray[]=  {datapin0,datapin1,datapin2,datapin3,
                      datapin4,datapin5,datapin6,datapin7};

uint8_t dataRoute[]=  {IC1,IC1,IC1,IC1,
                      IC1,IC1,IC1,IC1};

// IC2
#define dipPin1   0x10
#define dipPin2   0x11
#define dipPin3   0x12
#define dipPin4   0x13
#define dipPin5   0x14
#define dipPin6   0x15
#define dipPin7   0x16
#define dipPin8   0x17
#define dipPin9   0x18
#define dipPin10  0x19
#define dipPin11  0x1A
#define dipPin12  0x1B
#define dipPin13  0x1C
#define dipPin14  0x1D
#define dipPin15  0x1E

//#define dipPin16  // NO, NO! This is GND

// IC1
#define dipPin17  0x0
#define dipPin18  0x1
#define dipPin19  0x2
#define dipPin20  0x3
#define dipPin21  0x4
#define dipPin22  0x5
#define dipPin23  0x6
#define dipPin24  0x7
#define dipPin25  0x8
#define dipPin26  0x9
#define dipPin27  0xA
#define dipPin28  0xB
#define dipPin29  0xC
#define dipPin30  0xD
#define dipPin31  0xE

//#define dipPin32  // NO, NO! This is +5V

#endif

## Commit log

2025-12-12 public release
    [AC_Wiring.kicad_sch, CPU_board.kicad_sch, Floppy_Controller_Board.kicad_sch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]
2025-12-15 cleanup flags and statuses, fix types
    [300237-02.ghydra.c]

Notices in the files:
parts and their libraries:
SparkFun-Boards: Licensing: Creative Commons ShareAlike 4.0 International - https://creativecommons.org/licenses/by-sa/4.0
